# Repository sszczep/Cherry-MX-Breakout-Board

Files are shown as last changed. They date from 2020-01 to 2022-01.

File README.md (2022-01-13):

# Cherry MX Breakout Boards 
"Buy Me A Coffee" (https://www.buymeacoffee.com/sszczep)

<table>
 <tbody>
  <tr>
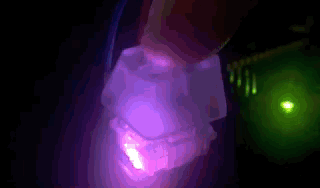
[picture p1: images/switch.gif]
   <td></td>
   <td>
    
Two breakout boards designed in **KiCad**. 

Both feature reverse-mounted addressable RGB LED **LTST-A683CEGBW**. 

Both are hot-swap capable (**Kailh Socket** / **Mill-Max 7305**).

Total board dimensions: **26 x 19 mm**.
   </td>
  </tr>
 </tbody>
</table>

**Mill-Max 7305 holes are compatible with standalone switches so they can be soldered directly to the board.**

| Schematic | PCB (Kailh Socket) | PCB (Mill-Max 7305) |
|---|---|---|
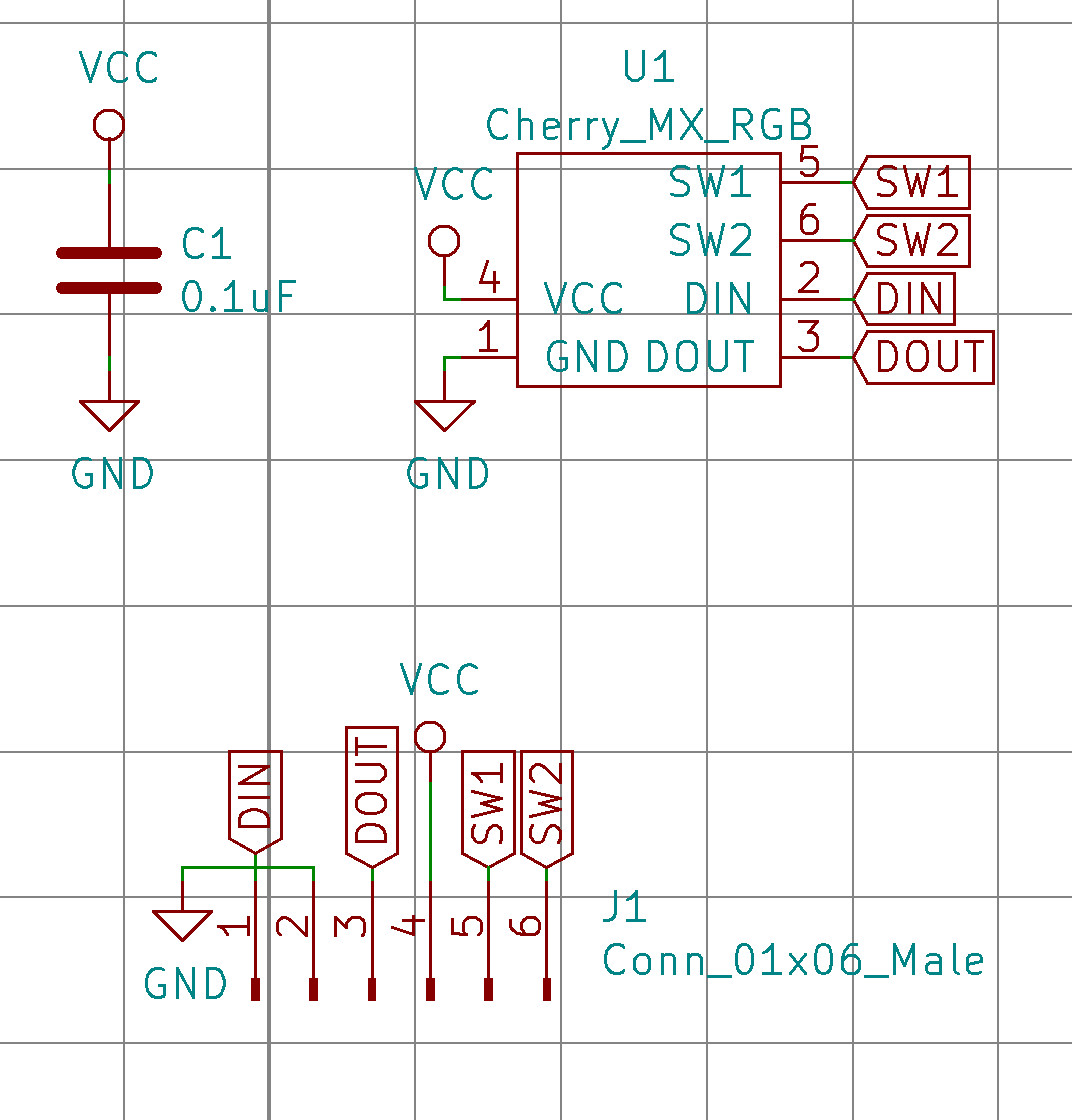
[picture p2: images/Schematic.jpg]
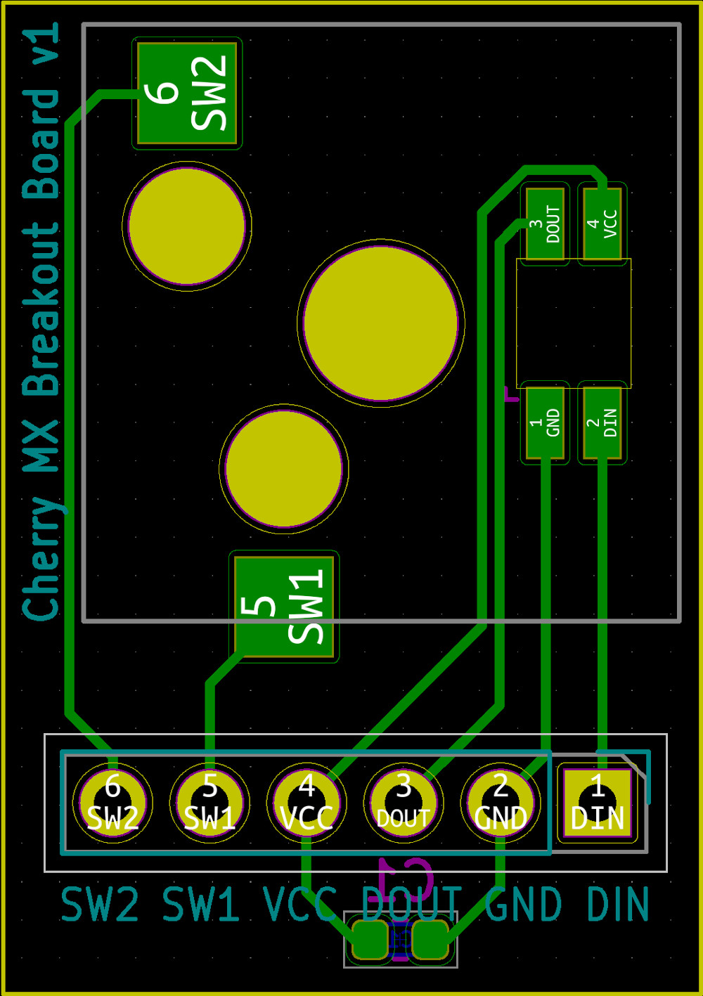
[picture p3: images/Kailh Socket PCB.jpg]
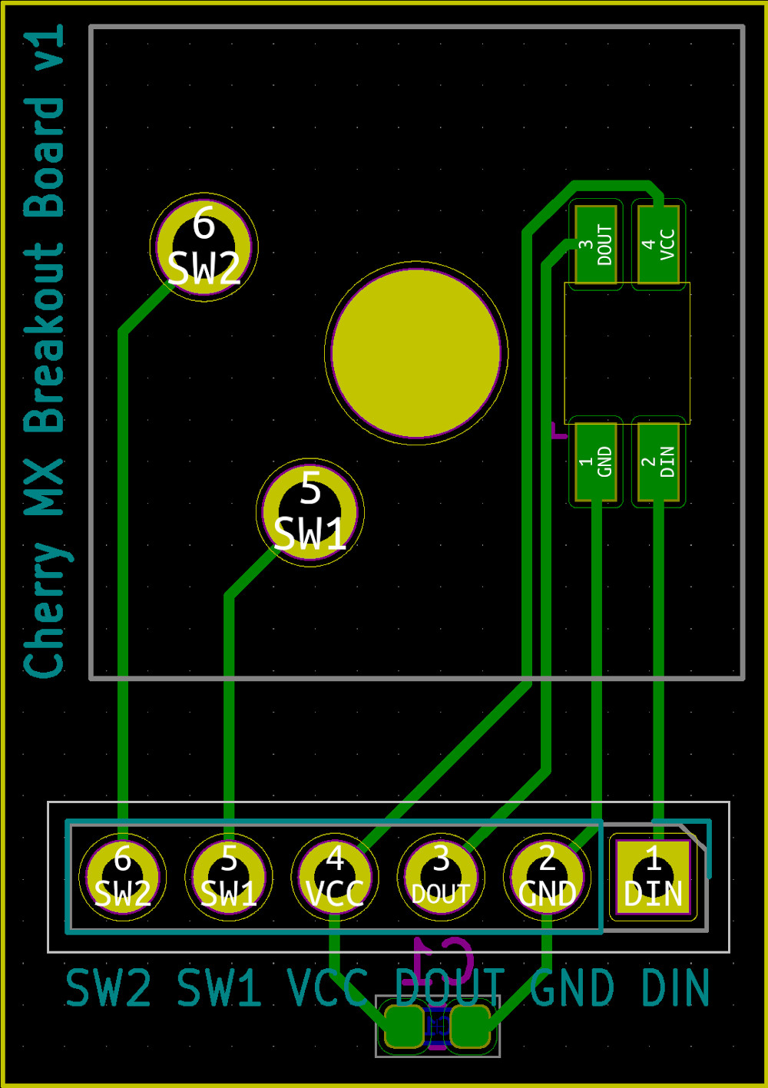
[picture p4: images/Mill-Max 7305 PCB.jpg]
|  |  |  |

## Kailh Socket Renders

| Top View | Bottom View |
|---|---|
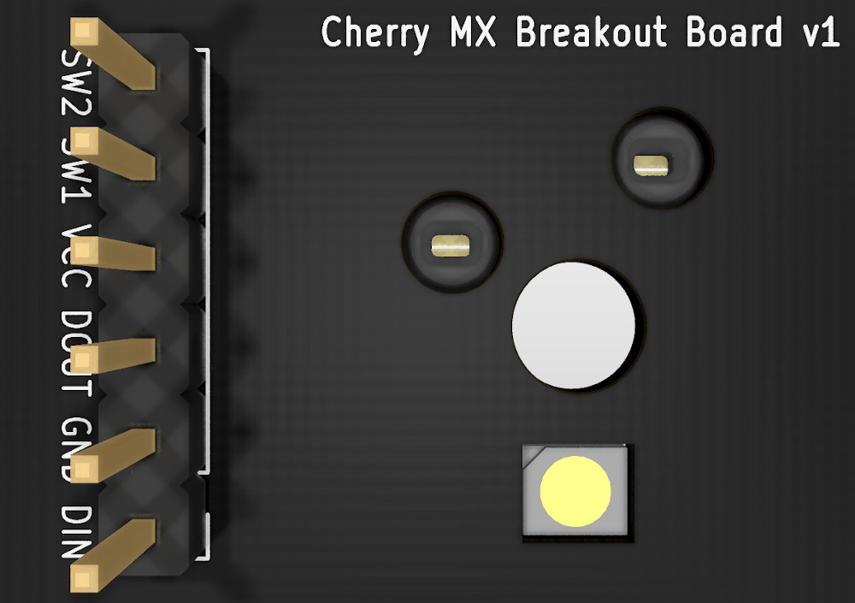
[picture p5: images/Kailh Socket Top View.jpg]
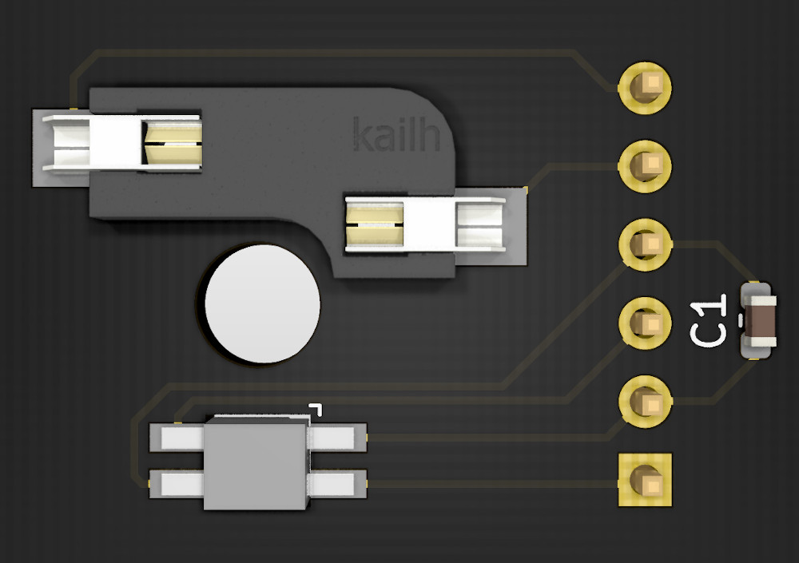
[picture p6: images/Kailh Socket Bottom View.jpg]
|  |  |

> Kailh Socket 3D Model was obtained from [*QMK*](https://github.com/qmk). All credits go to them. The exact file can be found [here](https://github.com/qmk/qmk_hardware/blob/master/components/kailh_socket_mx.stp).

## Mill-Max 7305 Renders

| Top View | Bottom View |
|---|---|
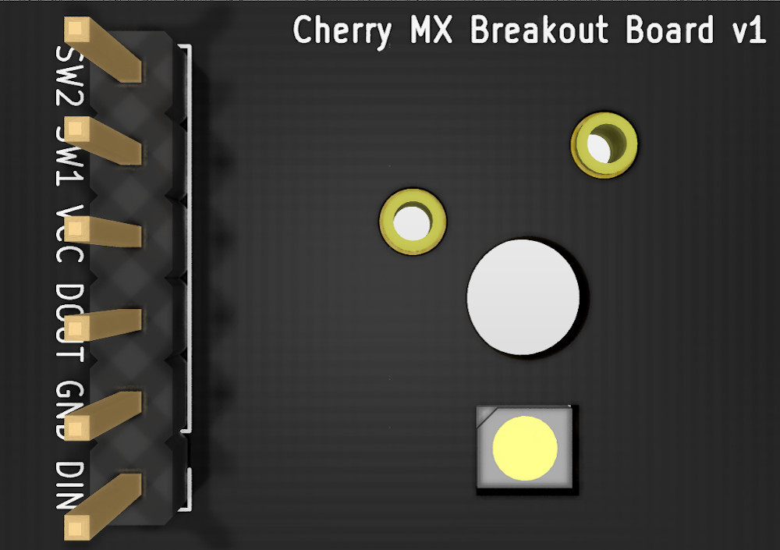
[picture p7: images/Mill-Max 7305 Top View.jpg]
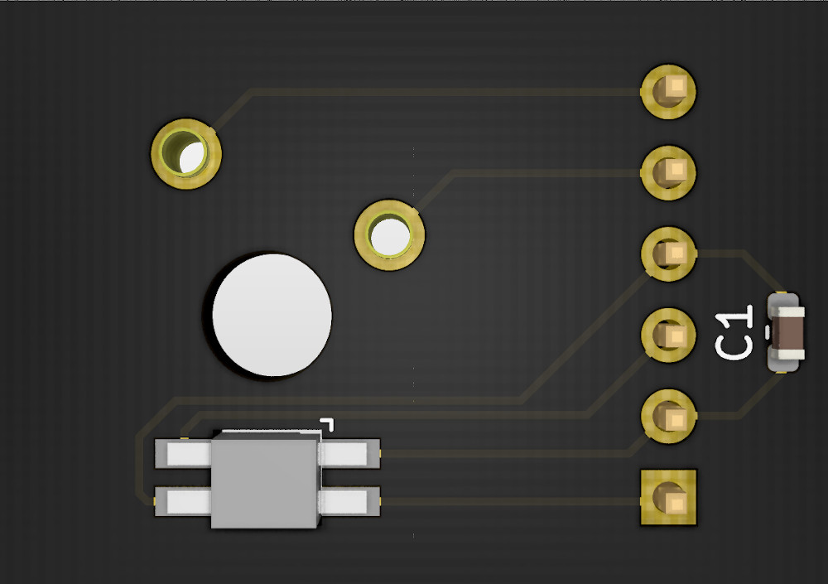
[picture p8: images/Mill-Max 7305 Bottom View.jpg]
|  |  |

## Real Photos
<table>
 <tbody>
  <tr>
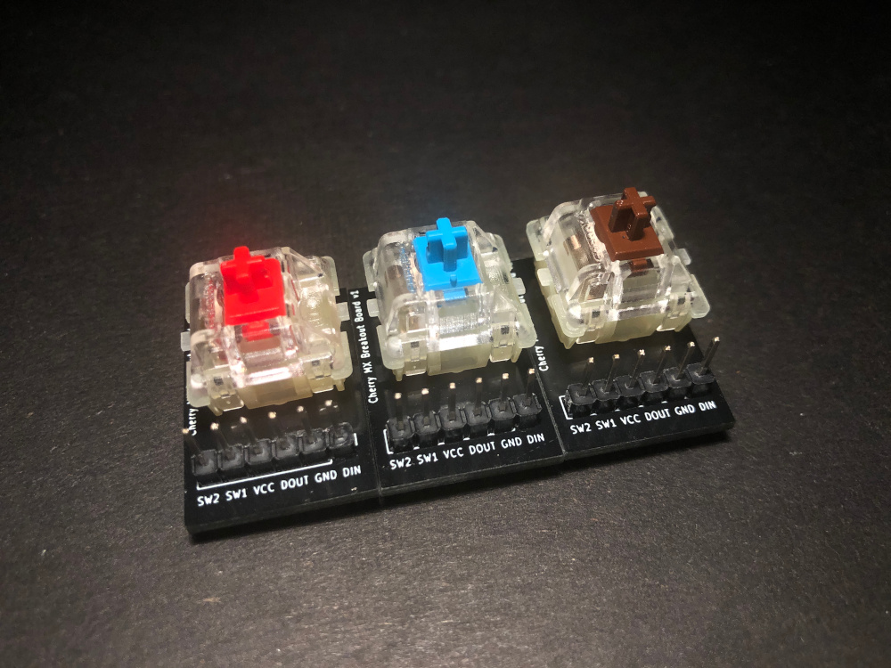
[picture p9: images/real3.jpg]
   <td colspan="3"></td>
  </tr>
  <tr>
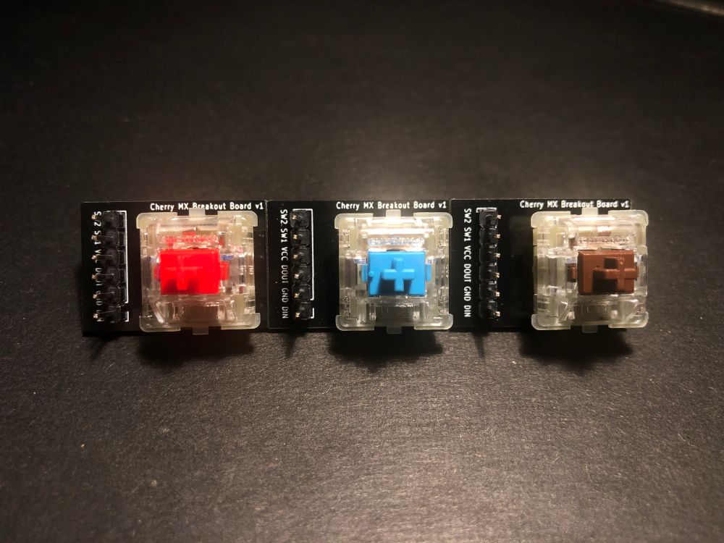
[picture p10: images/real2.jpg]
   <td></td>
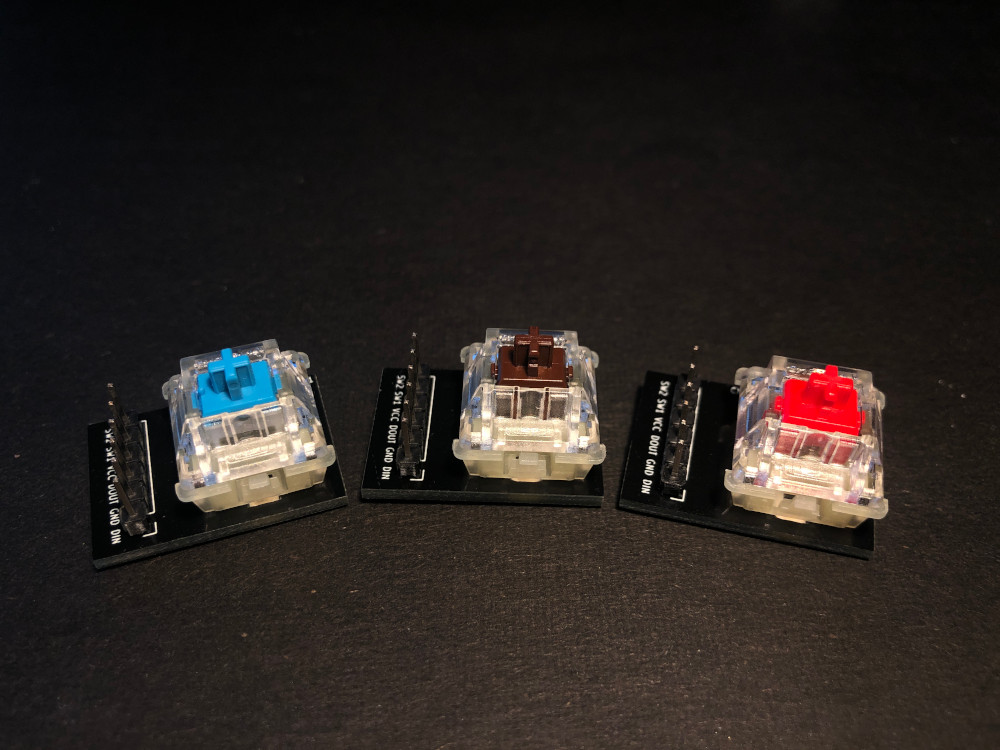
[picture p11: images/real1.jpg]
   <td></td>
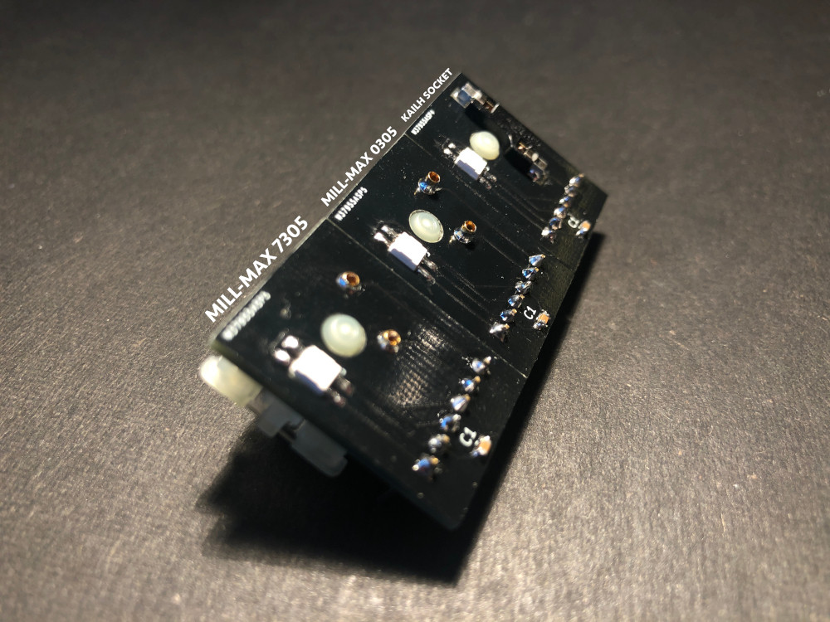
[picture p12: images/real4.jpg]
   <td></td>
  </tr>
  <tr>
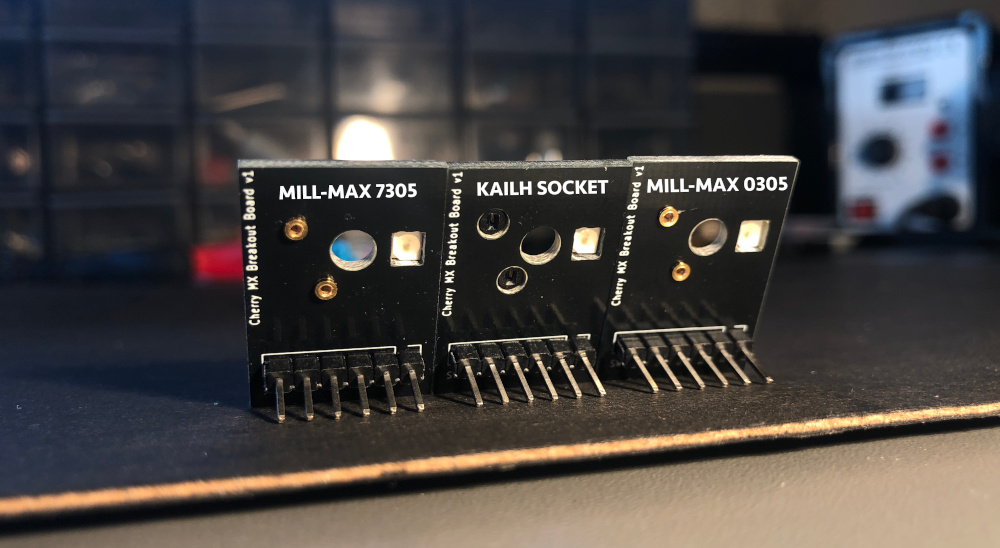
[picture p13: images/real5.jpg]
   <td></td>
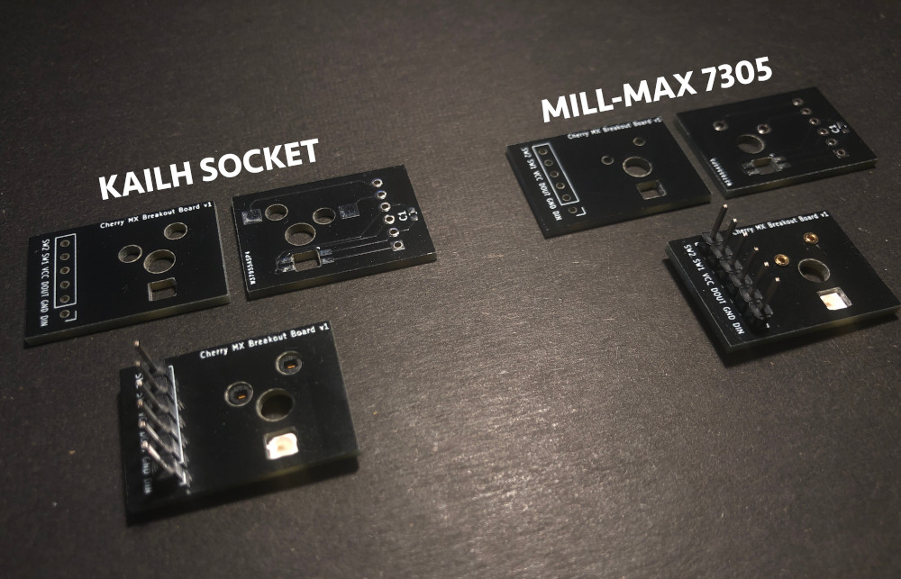
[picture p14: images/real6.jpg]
   <td></td>
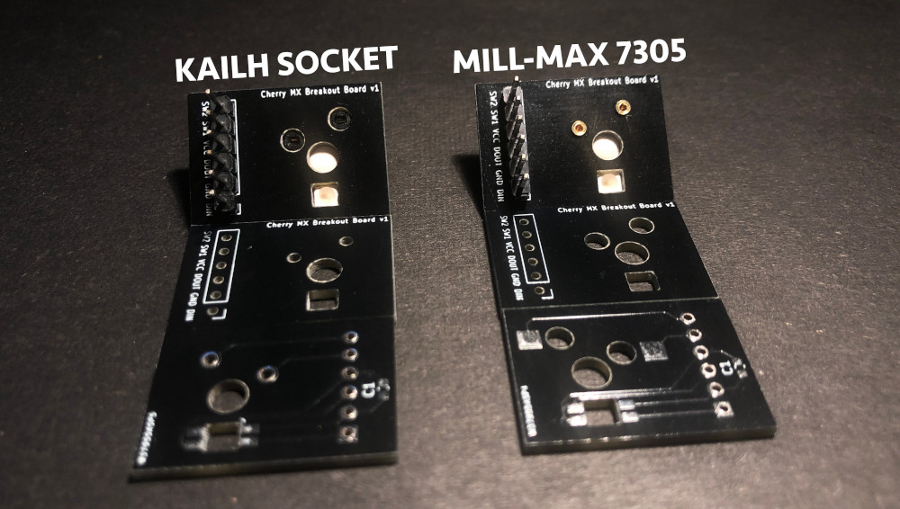
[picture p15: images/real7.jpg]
   <td></td>
  </tr>
 </tbody>
</table>

## Hooking up with Arduino
<table>
 <thead>
  <tr>
   <th>Code</th>
   <th>Wiring diagram</th>
  </tr>
 </thead>
 <tbody>
  <tr>
   <td><pre lang="cpp">
#include "FastLED.h"

    const int ledPin = 6;
    const int buttonPin = 7;

    int ledHue = 0;
    const int ledSaturation = 255;
    const int ledBrightness = 255;

    CRGB leds[1];

    void setup() {
      pinMode(buttonPin, INPUT_PULLUP);
      FastLED.addLeds<WS2811, ledPin>(leds, 1);
    }

    void loop() {
      if(digitalRead(buttonPin) == LOW) ledHue++;

      leds[0].setHSV(ledHue, ledSaturation, ledBrightness);
      FastLED.show();
    }
   </pre></td>
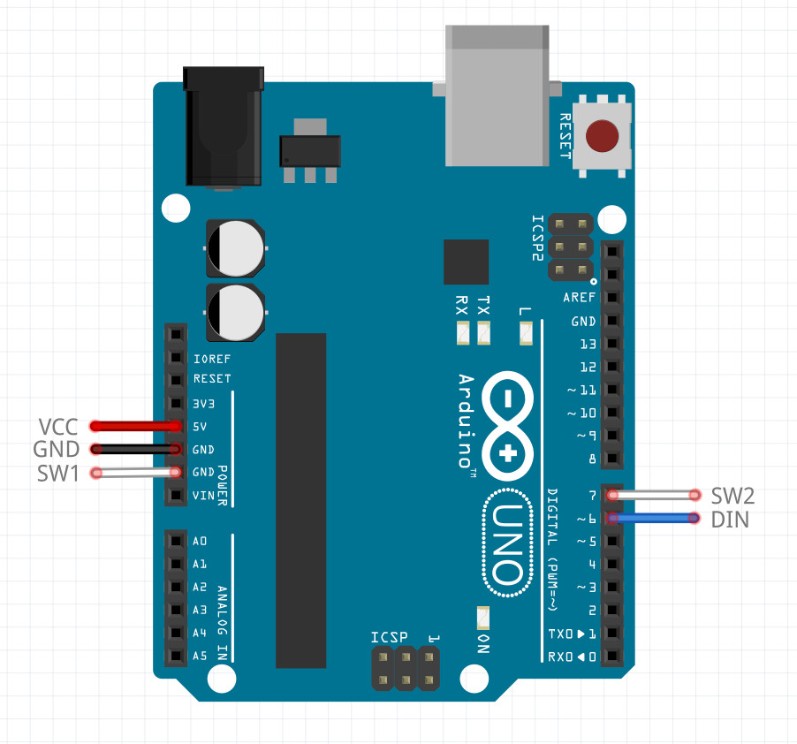
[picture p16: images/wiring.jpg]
   <td></td>
  </tr>
 </tbody>
</table>

## What socket is right for me?
<table>
 <thead>
  <tr>
   <td></td>
   <td>Kailh Socket</td>
   <td>Mill-Max 7305 & 0305</td>
  </tr>
 </thead>
 <tbody>
  <tr>
   <td>Cost per switch</td>
   <td>$0.10 on <a href="https://kbdfans.com/products/mechanical-keyboard-switches-kailh-pcb-socket">kbdfans.com</a></td>
   <td>about $0.88 on <a href="https://www.digikey.com/product-detail/en/mill-max-manufacturing-corp/7305-0-15-15-47-27-10-0/ED1039-ND/1765737">digikey.com</a></td>
  </tr>
  <tr>
   <td>Requires compatible PCB?</td>
   <td>Yes</td>
   <td>No</td>
  </tr>
  <tr>
   <td>Soldering difficulty</td>
   <td colspan="2">Both socket types are easy to solder and there shouldn't be any problems</td>
  </tr>
  <tr>
   <td>General Notes</td>
   <td colspan="2">Kailh Sockets are much cheaper when it comes to custom builds but require custom PCB. Mill-Max connectors are not as stabilized as they make an extra gap between PCB and switch. Mill-Max 7305 is preferable over 0305, it's thinner so the gap is not that wide. Swapping switches seems easier using Kailh Sockets, Mill-Max connectors tend to bend sockets' pins. In my opinion, Mill-Max connectors should be taken into an account only when you modify pre-existing PCB as they have no advantage over Kailh Sockets and simply cost more
  </tr>
 </tbody>
</table>

## Datasheets

  * [Cherry MX](https://github.com/sszczep/Cherry-MX-Breakout-Board/blob/master/datasheets/Cherry%20MX.pdf)
  * [LTST-A683CEGBW](https://github.com/sszczep/Cherry-MX-Breakout-Board/blob/master/datasheets/LTST-A683CEGBW.pdf)
  * [Kailh Socket](https://github.com/sszczep/Cherry-MX-Breakout-Board/blob/master/datasheets/Kailh%20Socket.pdf)
  * [Mill-Max](https://github.com/sszczep/Cherry-MX-Breakout-Board/blob/master/datasheets/Mill-Max.pdf)

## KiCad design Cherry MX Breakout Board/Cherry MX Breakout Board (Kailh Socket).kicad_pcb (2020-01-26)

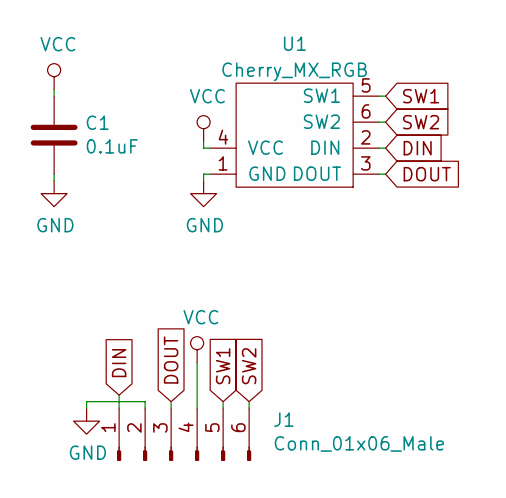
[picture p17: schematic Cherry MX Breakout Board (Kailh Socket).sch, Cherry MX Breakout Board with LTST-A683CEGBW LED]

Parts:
C1: 0.1uF; C_0603_1608Metric
J1: Conn_01x06_Male; PinHeader_1x06_P2.54mm_Vertical
U1: Cherry_MX_RGB; Cherry-MX_Plate-Mounted_LTST-A683CEGBW_Kailh_Socket

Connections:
DIN: J1.1, U1.2 (DIN)
DOUT: J1.3, U1.3 (DOUT)
GND: C1.2, J1.2, U1.1 (GND)
SW1: J1.5, U1.5 (SW1)
SW2: J1.6, U1.6 (SW2)
VCC: C1.1, J1.4, U1.4 (VCC)

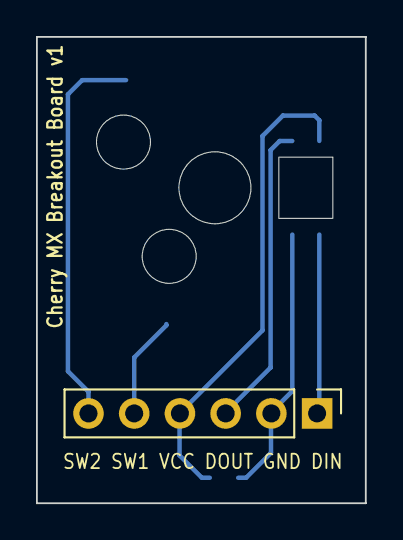
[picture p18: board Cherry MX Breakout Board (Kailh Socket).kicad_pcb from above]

Board: 2 copper layers, 18.3 x 25.9 mm, 3 parts (1 on the bottom side), 6 nets.

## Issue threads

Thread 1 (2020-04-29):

Thank you for making this

fgervais, 2020-04-29:
Are you thinking of selling the pcb on tindie or something similar?

sszczep, 2020-04-29:
Thanks for asking. I don’t think there will be enough interest. Having gerber files you can order this pcb for cheap.

Closed 2020-04-29.

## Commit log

2020-01-23 Update project files, add gerbers
    [Cherry MX Breakout Board (Kailh Socket)-B_Cu.gbr, Cherry MX Breakout Board (Kailh Socket)-B_Mask.gbr, Cherry MX Breakout Board (Kailh Socket)-B_SilkS.gbr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]
2020-01-26 Fix footprints and PCBs
    - removed silkscreen of Cherry MX and Kailh Socket
    - LTST-A683CEGBW pinout and model was rotated which caused invalid connections
    [Cherry MX Breakout Board (Kailh Socket)-B_Cu.gbr, Cherry MX Breakout Board (Kailh Socket)-B_Mask.gbr, Cherry MX Breakout Board (Kailh Socket)-B_SilkS.gbr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]
2020-03-29 Fix Arduino code
2020-04-01 Add PCB Mounted footprints

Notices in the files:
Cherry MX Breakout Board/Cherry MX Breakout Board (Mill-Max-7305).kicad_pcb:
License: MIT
